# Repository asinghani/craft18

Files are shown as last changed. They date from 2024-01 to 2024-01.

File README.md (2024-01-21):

# Craft18

Bring Minecraft Redstone circuits to life using Craft18, our physical re-creation of the game’s “circuit” mechanics using only discrete analog components. Look ma, no microcontrollers! To build even more complex circuits, link the physical world to the virtual world using our custom game plugin and game-to-physical bridge!

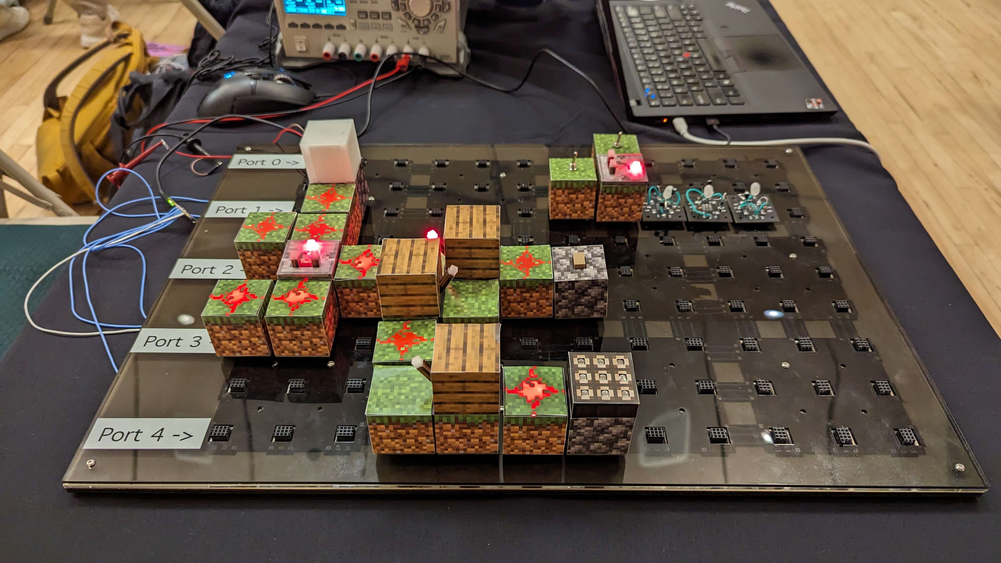
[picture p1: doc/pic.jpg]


Also see our [circuit diagrams PDF](doc/schem.pdf) to see how each circuit is implemented!

## Repo Structure

- [3D printable CAD models for each block](3d_cad/)
- [Texture images for each block](textures/)
- [Raw circuit schematic files](schematics/)
- [Spigot plugin for physical-to-virtual bridge](craft18_plugin/)
- [Software for physical-to-virtual bridge](craft18duino/)
- [Baseplate CAD files](2d_cad/)
- [Connector board layouts](boards/)

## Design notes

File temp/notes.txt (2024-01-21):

Blocks we need to build: (LxH)

btn height = 3.175mm + 2px = 7.9375mm ~= 7.9mm

btn = 8mm x 13mm

holes 5.7mm apart

holes 2.8mm high
holes 1.1mm wide

btn profile = 
10.3mm x 4.8mm

minus 3.5mm hole on one 10.3mm side

16px = 1.5in = 38.1mm

1px = 0.09375in = 2.38125mm

plate thickness (top of base plate to bottom of block plate):
0.428in

account for screw head diameter as well

repeater torch bottom hole
1/8" x 1/8" x 0.2in

- iron door textures: 4
- torch side textures: 90
- torch top textures: 30

- grass side textures: 150
- grass top textures: 10

- wood textures: 30
- cobblestone textures: 25
- repeater top textures: 8
- comparator top textures: 8
- repeater/comparator side textures: 35

- redstone lamp textures: 20

- redstone dust X textures: 20
- redstone dust line textures: 10

- daylight sensor top textures: 2
- daylight sensor side textures: 6

1 iron door (1x3)
	- grass block + iron door on top + space for servo
	- need to measure out servo dimensions to figure out fit

repeater slider top half (small)
button top half (small)
lever stone piece (small)

print more torch tops
print more 5mm diffusers

daylight sensor print ring + top half

5mm LED diffuser attempt (small, PETG)

make 14x torch caps

3 torches (2x2) ++
	- 2x grass block (base) + some block (wood) + torch on the side

5 repeaters (1x1.5) ++
	- grass block with repeater on top with switch + output indicator LED in the repeater

2 comparators (1x1.5) ++
	- grass block with comparator on top with + 2x output indicator LEDs on the back + always-on LED in the front

1 button (1x1.5) **** ++
	- grass block + up facing wooden button
	- button = 14.2875 W x 9.525 L x 4.7625 H
		     = 6 x 

3 levers (1x1.5) **** ++
	- grass block + up facing lever switch
	- lever base = 19.05 W x 14.2875 L x 7.14375 H
				 = 8 x 6 x 3

2 redstone lamps (1x2) **** ++
	- grass block + hollow-ish redstone lamp
	- top half printed in translucent
	- bottom half is generic block with round hole

1 daylight sensor (1x1.5) 
	- grass block + daylight sensor texture + 9x photocell
	- see solidworks file for top half
	- bottom half is generic block with round hole
	- height = 6px // 14.2875mm
	- 3.5mm base test = 1.5px

15 redstone dust (1x1)  ****
	- 3 straight 12 X
	- grass block + redstone dust + holes for light to shine through

Textures we need:
	- green grass textures (all 6 sides)
		- make sure it matches the game, the textures in the file are inconsistent
	- comparator textures
	- block-side-mount torch textures
	- redstone lamp textures
	- iron door textures
	- redstone dust on grass textures (note there's 2 separate textures for X axis and Y axis)
	- redstone dust "cross" on grass textures
	- wooden button texture
	- lever textures
	- daylight sensor texture
	- note block texture

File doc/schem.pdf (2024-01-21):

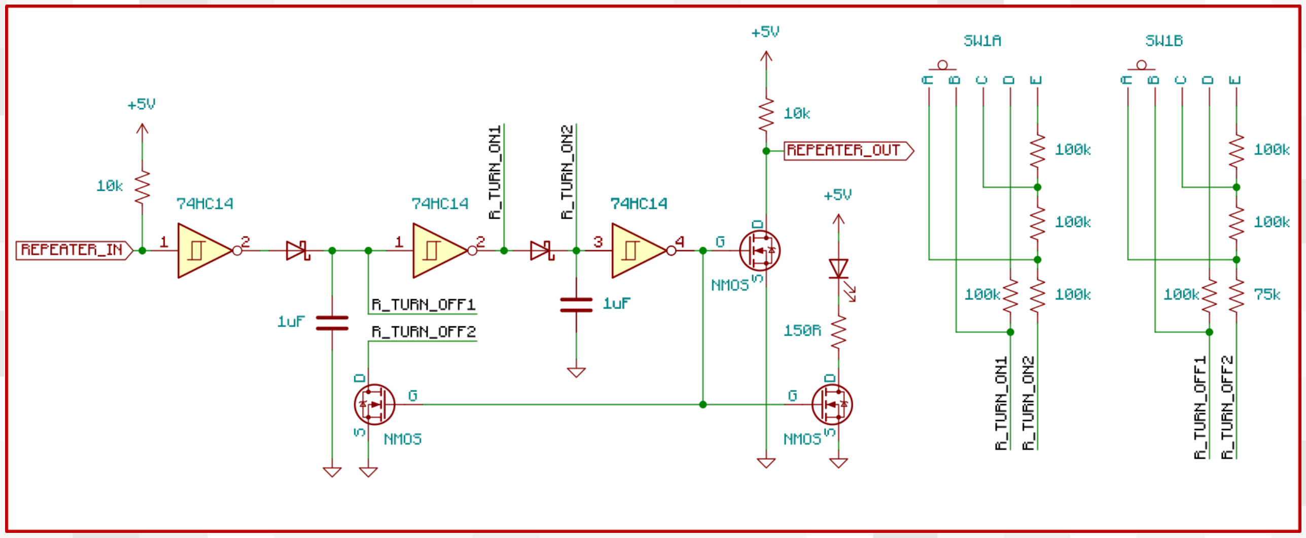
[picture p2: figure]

# Repeater

Produces a full-strength output signal (https://minecraft.wiki/w/Redstone_Dust) from its front when its back is powered, with four configurable delay settings.

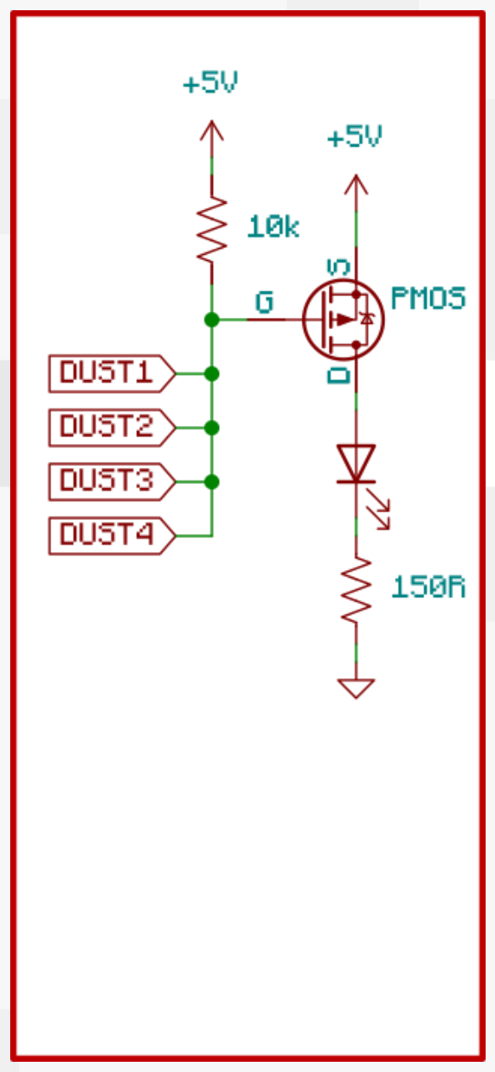
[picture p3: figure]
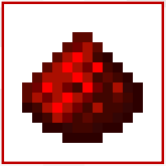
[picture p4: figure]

# Redstone Dust

Can transmit redstone power as a wire when placed as a block.

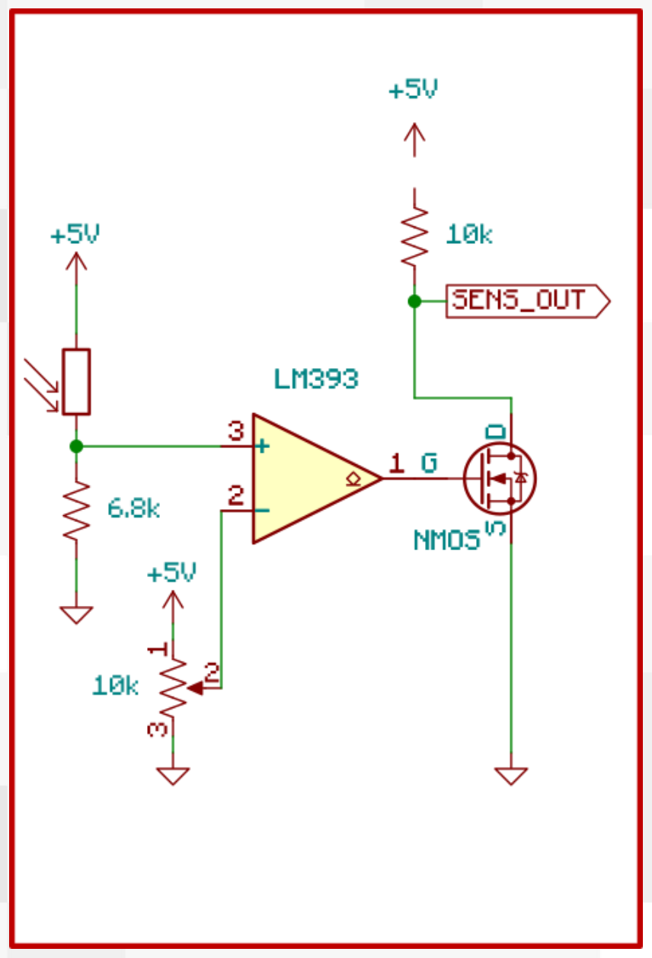
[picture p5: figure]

# Daylight Detector

Outputs a redstone signal based on sunlight.

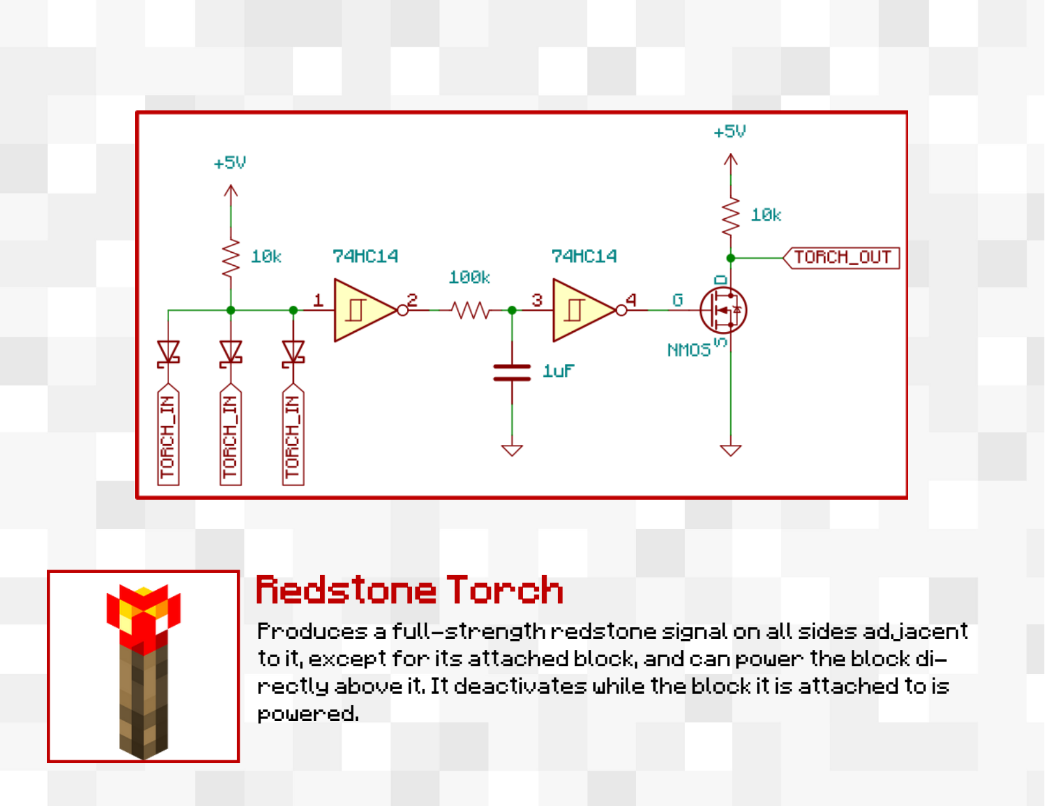
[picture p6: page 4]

# Redstone Torch

Produces a full-strength redstone signal on all sides adjacent to it, except for its attached block, and can power the block directly above it. It deactivates while the block it is attached to is powered.

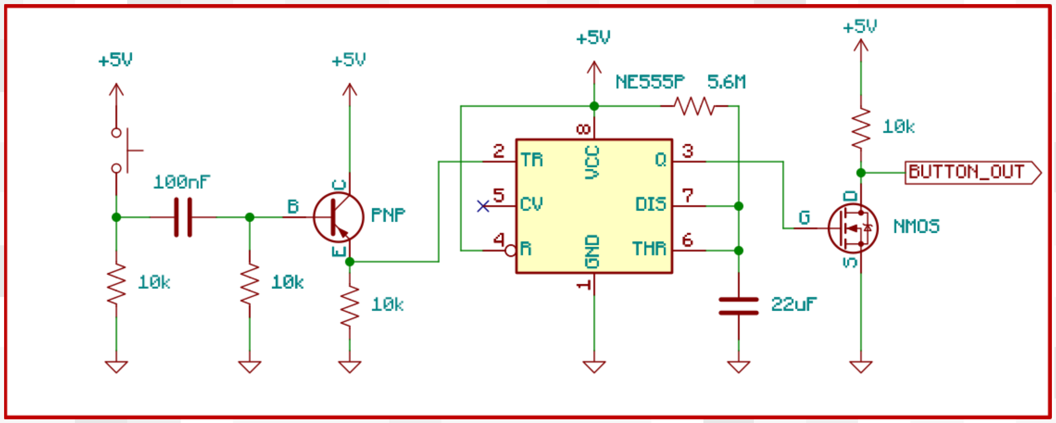
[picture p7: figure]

# Button

Produces a temporary redstone signal when pressed.

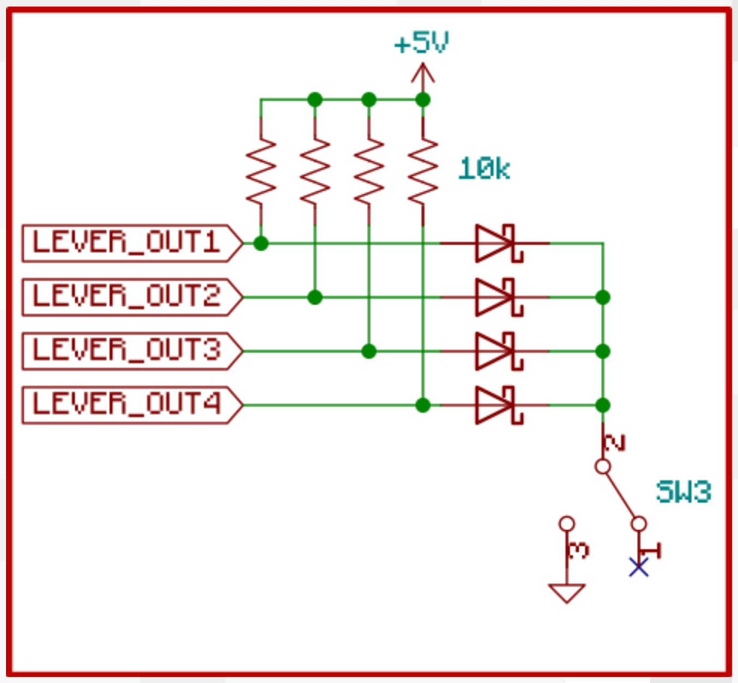
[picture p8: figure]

# Lever

Can provide switchable redstone power.

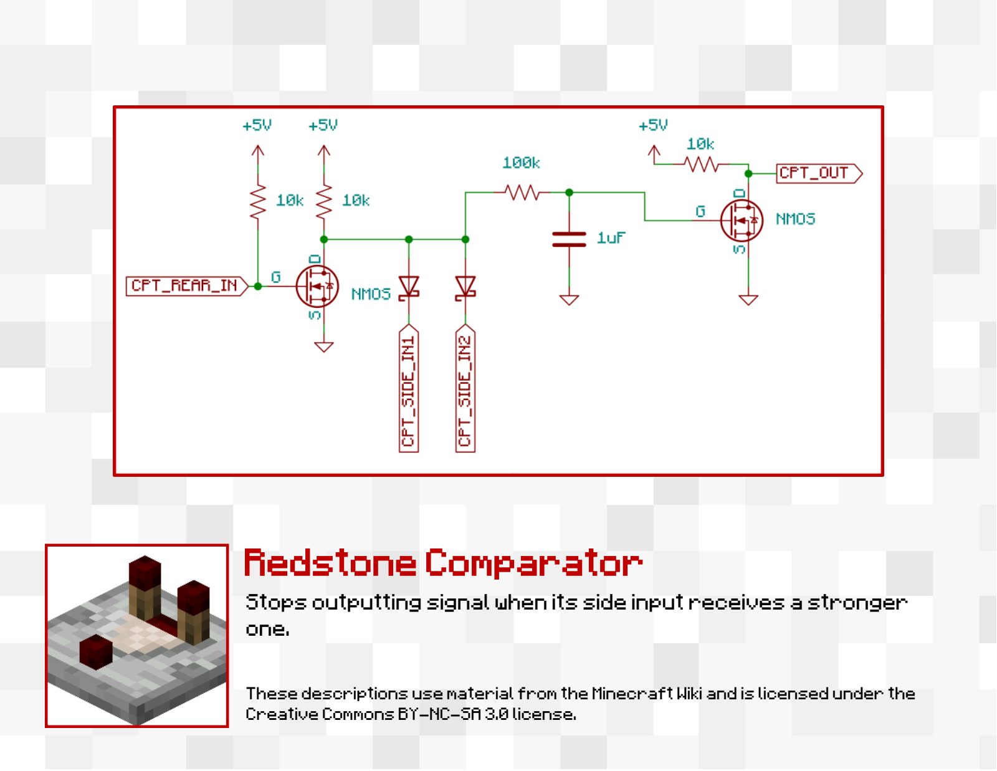
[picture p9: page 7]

# Redstone Comparator

Stops outputting signal when its side input receives a stronger one.

These descriptions use material from the Minecraft Wiki and is licensed under the Creative Commons BY-NC-SA 3.0 license.

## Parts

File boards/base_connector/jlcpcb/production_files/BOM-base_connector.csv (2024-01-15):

Comment | Designator | Footprint | LCSC
MountingHole | H2 | MountingHole_3.2mm_M3
DNF | R8 | R_0805_2012Metric_Pad1.20x1.40mm_HandSolder
VCC | TP5 | TestPoint_THTPad_2.5x2.5mm_Drill1.2mm
TestPoint | TP1 | TestPoint_THTPad_2.5x2.5mm_Drill1.2mm
GND | TP7 | TestPoint_THTPad_2.5x2.5mm_Drill1.2mm
MountingHole | H1 | MountingHole_3.2mm_M3
DNF | R7 | R_0805_2012Metric_Pad1.20x1.40mm_HandSolder
MountingHole | H4 | MountingHole_3.2mm_M3
DNF | R2 | R_0805_2012Metric_Pad1.20x1.40mm_HandSolder
~ | U1 | 3x3conn
DNF | R5 | R_0805_2012Metric_Pad1.20x1.40mm_HandSolder
TestPoint | TP4 | TestPoint_THTPad_2.5x2.5mm_Drill1.2mm
VCC | TP6 | TestPoint_THTPad_2.5x2.5mm_Drill1.2mm
TestPoint | TP3 | TestPoint_THTPad_2.5x2.5mm_Drill1.2mm
DNF | R4 | R_0805_2012Metric_Pad1.20x1.40mm_HandSolder
GND | TP8 | TestPoint_THTPad_2.5x2.5mm_Drill1.2mm
DNF | R1 | R_0805_2012Metric_Pad1.20x1.40mm_HandSolder
MountingHole | H3 | MountingHole_3.2mm_M3
TestPoint | TP2 | TestPoint_THTPad_2.5x2.5mm_Drill1.2mm
DNF | R3 | R_0805_2012Metric_Pad1.20x1.40mm_HandSolder
DNF | R6 | R_0805_2012Metric_Pad1.20x1.40mm_HandSolder

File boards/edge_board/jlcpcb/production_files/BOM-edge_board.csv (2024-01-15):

Comment | Designator | Footprint | LCSC
MountingHole | H2 | MountingHole_2.2mm_M2
MountingHole | H4 | MountingHole_2.2mm_M2
Conn_01x03 | J2 | connfemale
MountingHole | H3 | MountingHole_2.2mm_M2
MountingHole | H1 | MountingHole_2.2mm_M2
Conn_01x03 | J1 | connmale
SIG | TP2 | TestPoint_THTPad_3.0x3.0mm_Drill1.5mm
R_US | R1 | R_0805_2012Metric_Pad1.20x1.40mm_HandSolder
VCC | TP1 | TestPoint_THTPad_3.0x3.0mm_Drill1.5mm
GND | TP3 | TestPoint_THTPad_3.0x3.0mm_Drill1.5mm
R_US | R2 | R_0805_2012Metric_Pad1.20x1.40mm_HandSolder

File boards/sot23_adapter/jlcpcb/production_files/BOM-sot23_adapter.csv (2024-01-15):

Comment | Designator | Footprint | LCSC
Conn_01x03 | J3 | PinHeader_1x03_P2.54mm_Vertical
Conn_01x03 | J2 | PinHeader_1x03_P2.54mm_Vertical
SOT23 | J1 | TSOT-23-6_HandSoldering

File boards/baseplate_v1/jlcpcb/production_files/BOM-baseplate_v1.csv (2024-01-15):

Comment | Designator | Footprint | LCSC
TestPoint | TP9 | edge_pad
~ | U9 | 3x3conn
TestPoint | TP35 | edge_pad
TestPoint | TP11 | edge_pad
~ | U5 | 3x3conn
~ | U1 | 3x3conn
TestPoint | TP5 | edge_pad
TestPoint | TP25 | edge_pad
TestPoint | TP4 | edge_pad
~ | U4 | 3x3conn
TestPoint | TP20 | edge_pad
~ | U8 | 3x3conn
TestPoint | TP26 | edge_pad
TestPoint | TP31 | edge_pad
~ | U3 | 3x3conn
~ | U2 | 3x3conn
TestPoint | TP16 | edge_pad
TestPoint | TP27 | edge_pad
TestPoint | TP17 | edge_pad
TestPoint | TP8 | edge_pad
TestPoint | TP7 | edge_pad
TestPoint | TP19 | edge_pad
TestPoint | TP18 | edge_pad
TestPoint | TP34 | edge_pad
TestPoint | TP6 | edge_pad
TestPoint | TP12 | edge_pad
TestPoint | TP2 | edge_pad
TestPoint | TP15 | edge_pad
TestPoint | TP32 | edge_pad
TestPoint | TP30 | edge_pad
TestPoint | TP10 | edge_pad
~ | U7 | 3x3conn
TestPoint | TP29 | edge_pad
~ | U6 | 3x3conn
TestPoint | TP36 | edge_pad
TestPoint | TP28 | edge_pad
TestPoint | TP14 | edge_pad
TestPoint | TP1 | edge_pad
TestPoint | TP22 | edge_pad
TestPoint | TP33 | edge_pad
TestPoint | TP24 | edge_pad
TestPoint | TP13 | edge_pad
TestPoint | TP23 | edge_pad
TestPoint | TP21 | edge_pad
TestPoint | TP3 | edge_pad

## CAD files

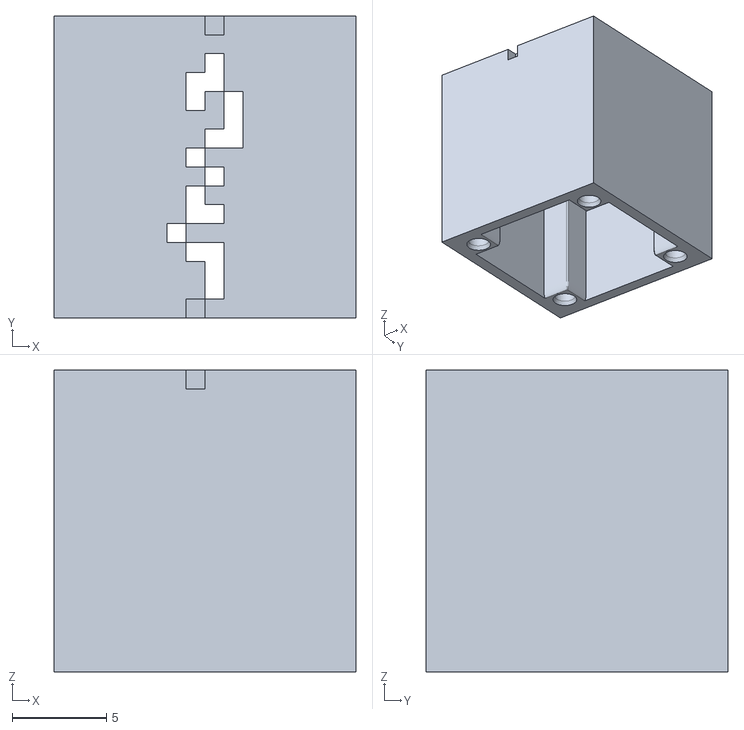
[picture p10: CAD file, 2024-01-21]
3d_cad/redstone_wire_straight.stl
16.0 x 16.0 x 16.0

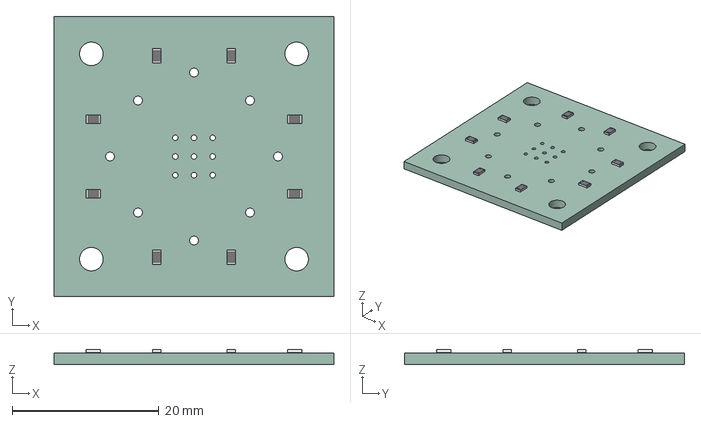
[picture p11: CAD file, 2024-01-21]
boards/base_connector/base_connector.step
38.1 x 38.1 x 2.10 mm
base_connector PCB

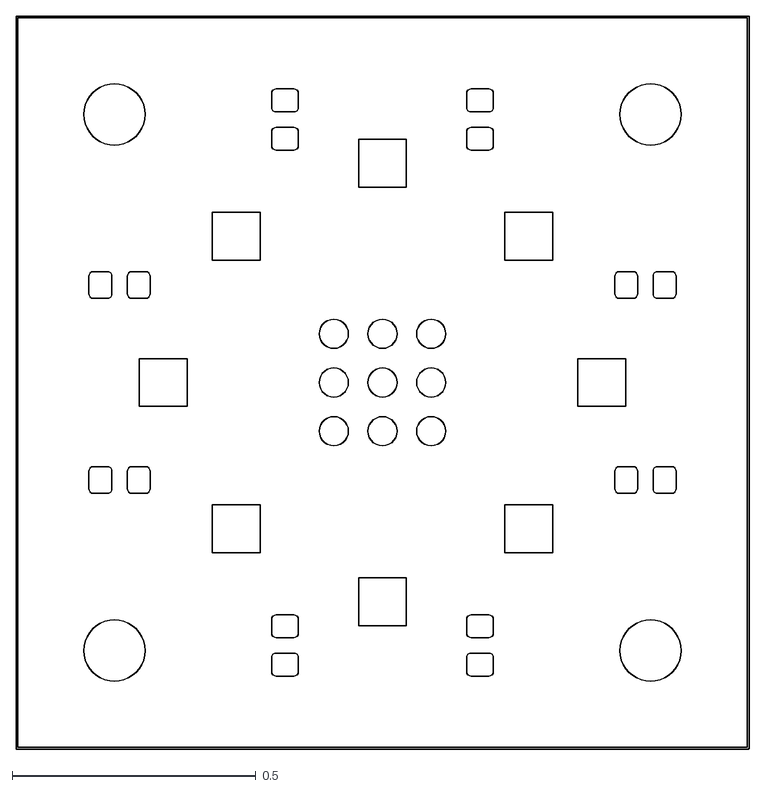
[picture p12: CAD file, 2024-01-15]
boards/base_connector/dxf/base_connector-Edge_Cuts.dxf
1.50 x 1.50

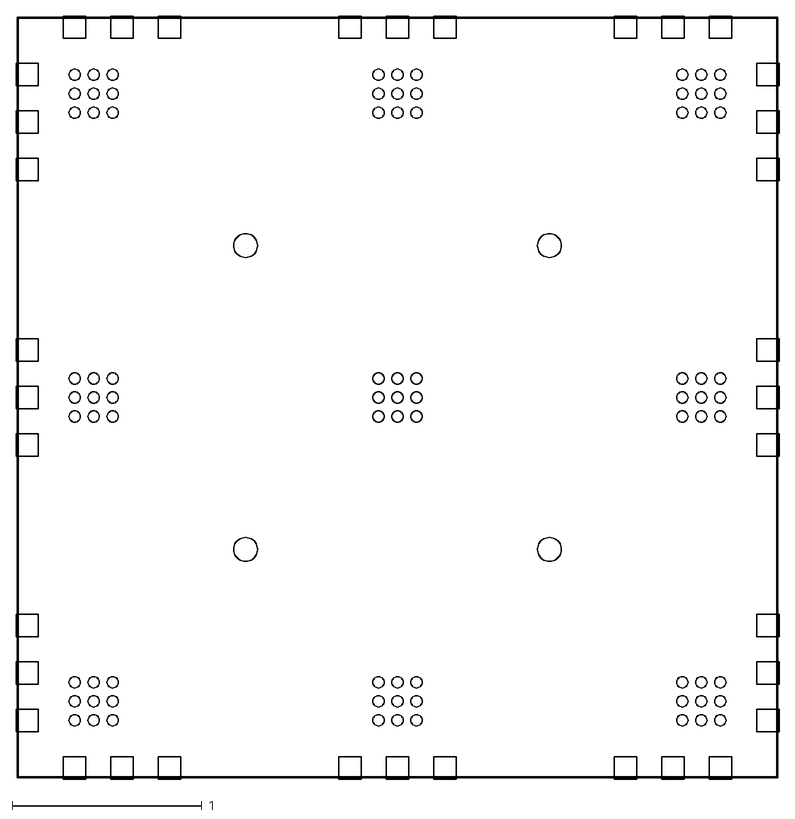
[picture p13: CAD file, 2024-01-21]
boards/baseplate_v1/dxf/baseplate_v1-Edge_Cuts.dxf
4.02 x 4.02

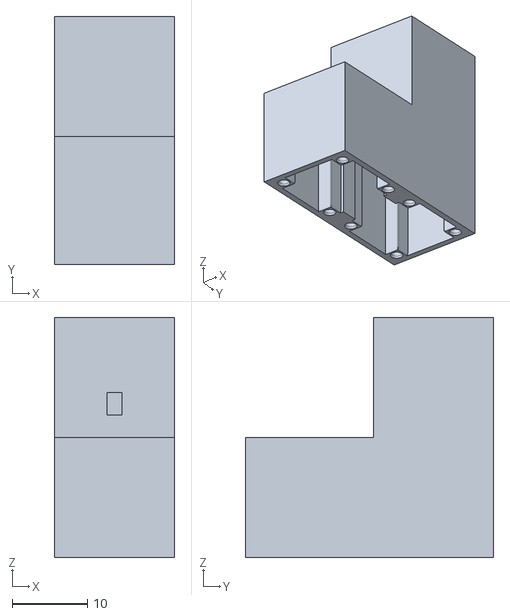
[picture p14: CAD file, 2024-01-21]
3d_cad/torch_base.stl
16.0 x 33.0 x 32.0

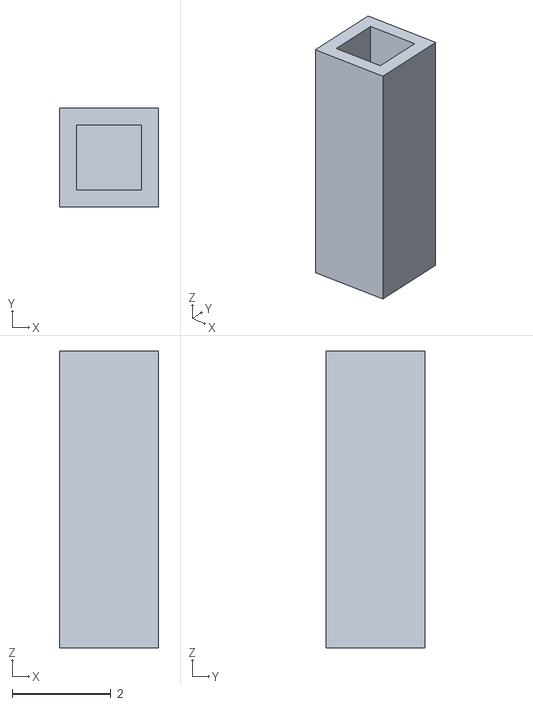
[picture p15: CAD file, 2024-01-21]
3d_cad/repeater_switch_cap.stl
2.00 x 2.00 x 6.00

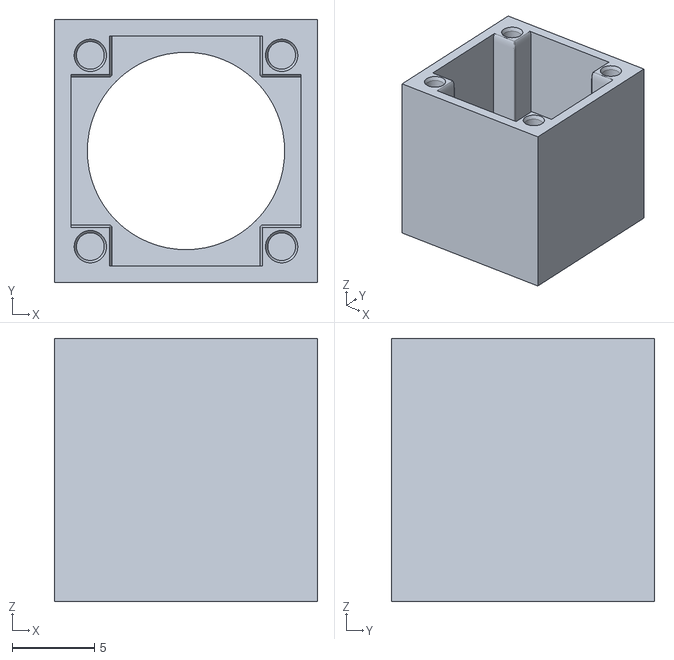
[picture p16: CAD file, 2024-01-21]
3d_cad/generic_bottom_half.stl
16.0 x 16.0 x 16.0

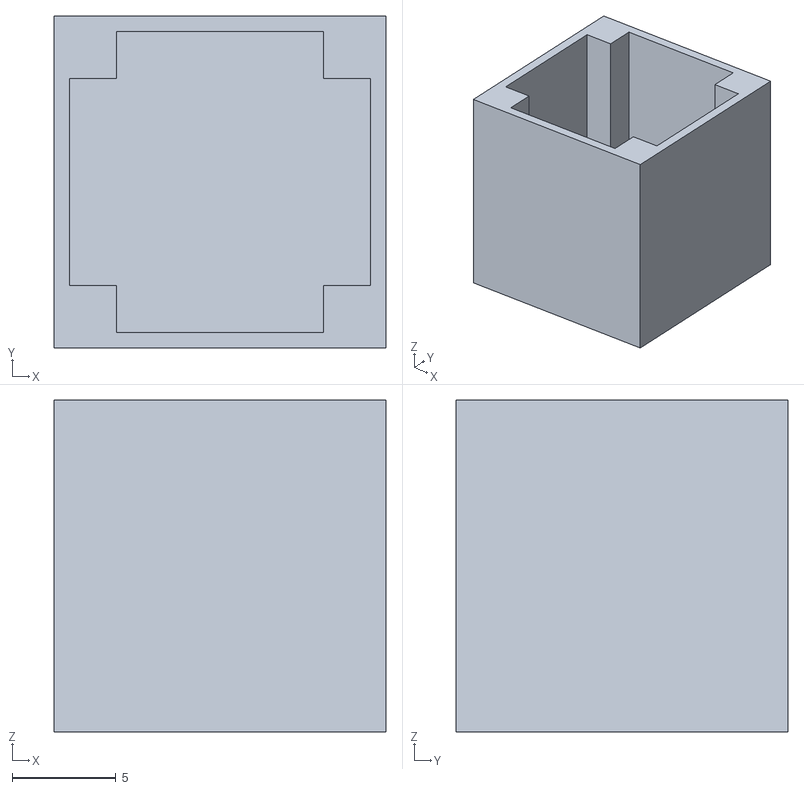
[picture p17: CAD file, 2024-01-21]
3d_cad/lamp_top_transparent.stl
16.0 x 16.0 x 16.0

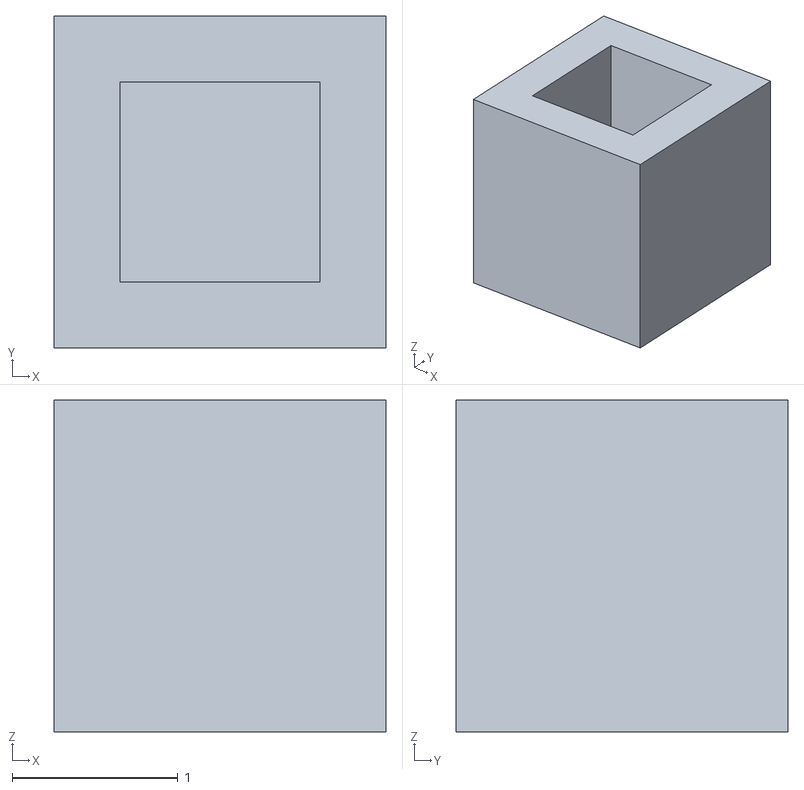
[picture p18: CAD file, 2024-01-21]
3d_cad/redstone_torch_cap.stl
2.00 x 2.00 x 2.00

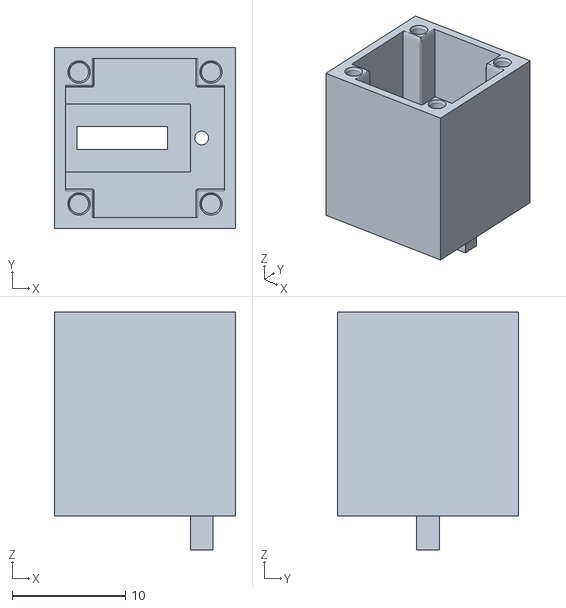
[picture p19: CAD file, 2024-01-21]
3d_cad/repeater.stl
16.0 x 16.0 x 21.0

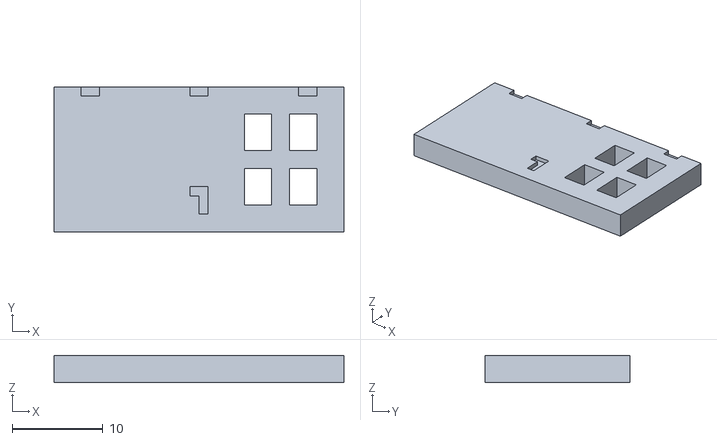
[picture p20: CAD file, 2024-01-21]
3d_cad/door.stl
32.0 x 16.0 x 3.00

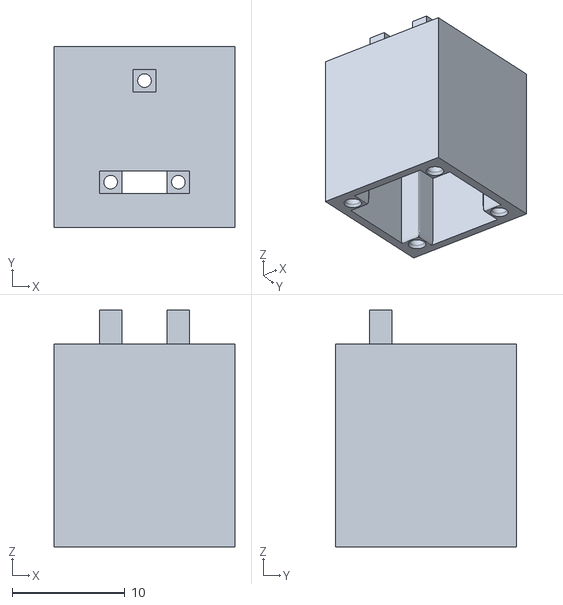
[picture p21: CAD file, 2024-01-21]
3d_cad/comparator.stl
16.0 x 16.0 x 21.0

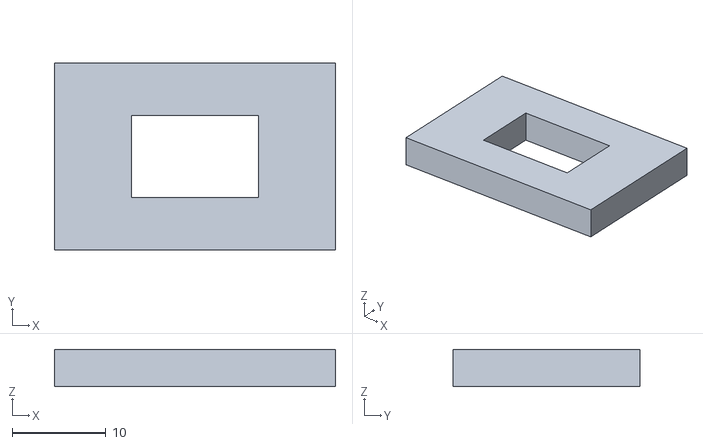
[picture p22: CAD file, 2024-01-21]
3d_cad/button_spacer_prescaled.stl
30.0 x 20.0 x 4.00

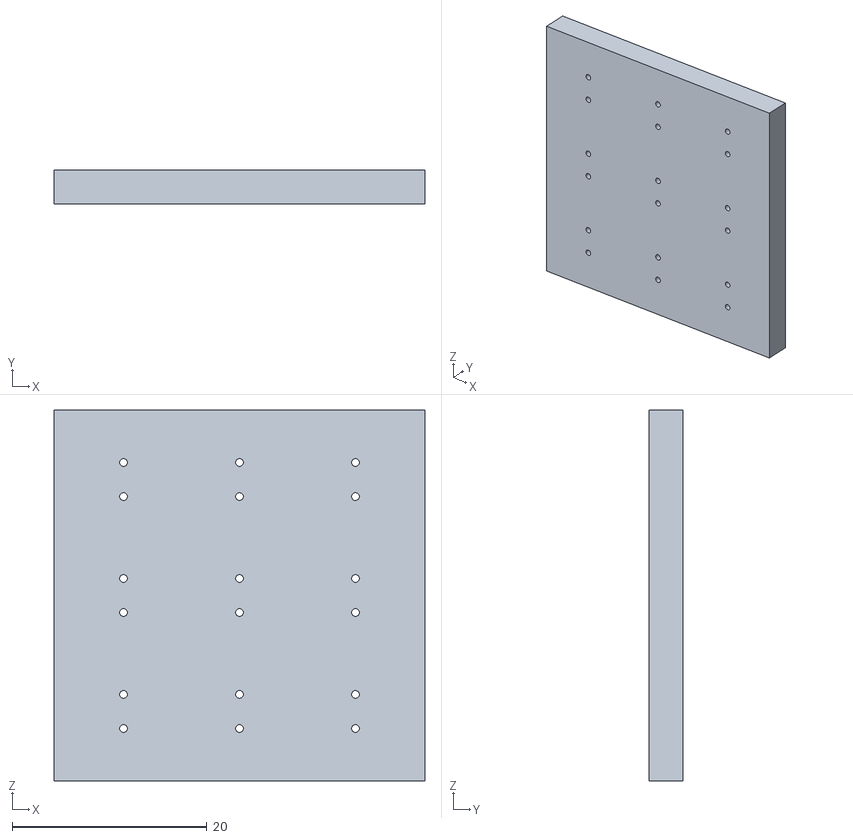
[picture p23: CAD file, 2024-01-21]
3d_cad/daylight_sensor_top.STL
38.1 x 3.50 x 38.1

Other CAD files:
2d_cad/base_board.dwg
3d_cad/button.stl
3d_cad/redstone_wire_cross.stl
3d_cad/lever.stl
3d_cad/button_top_prescaled.stl
3d_cad/daylight_sensor_frame.stl
3d_cad/torch_light.stl
boards/base_connector/dxf/base_connector-B_Mask.dxf
boards/base_connector/dxf/base_connector-F_Mask.dxf

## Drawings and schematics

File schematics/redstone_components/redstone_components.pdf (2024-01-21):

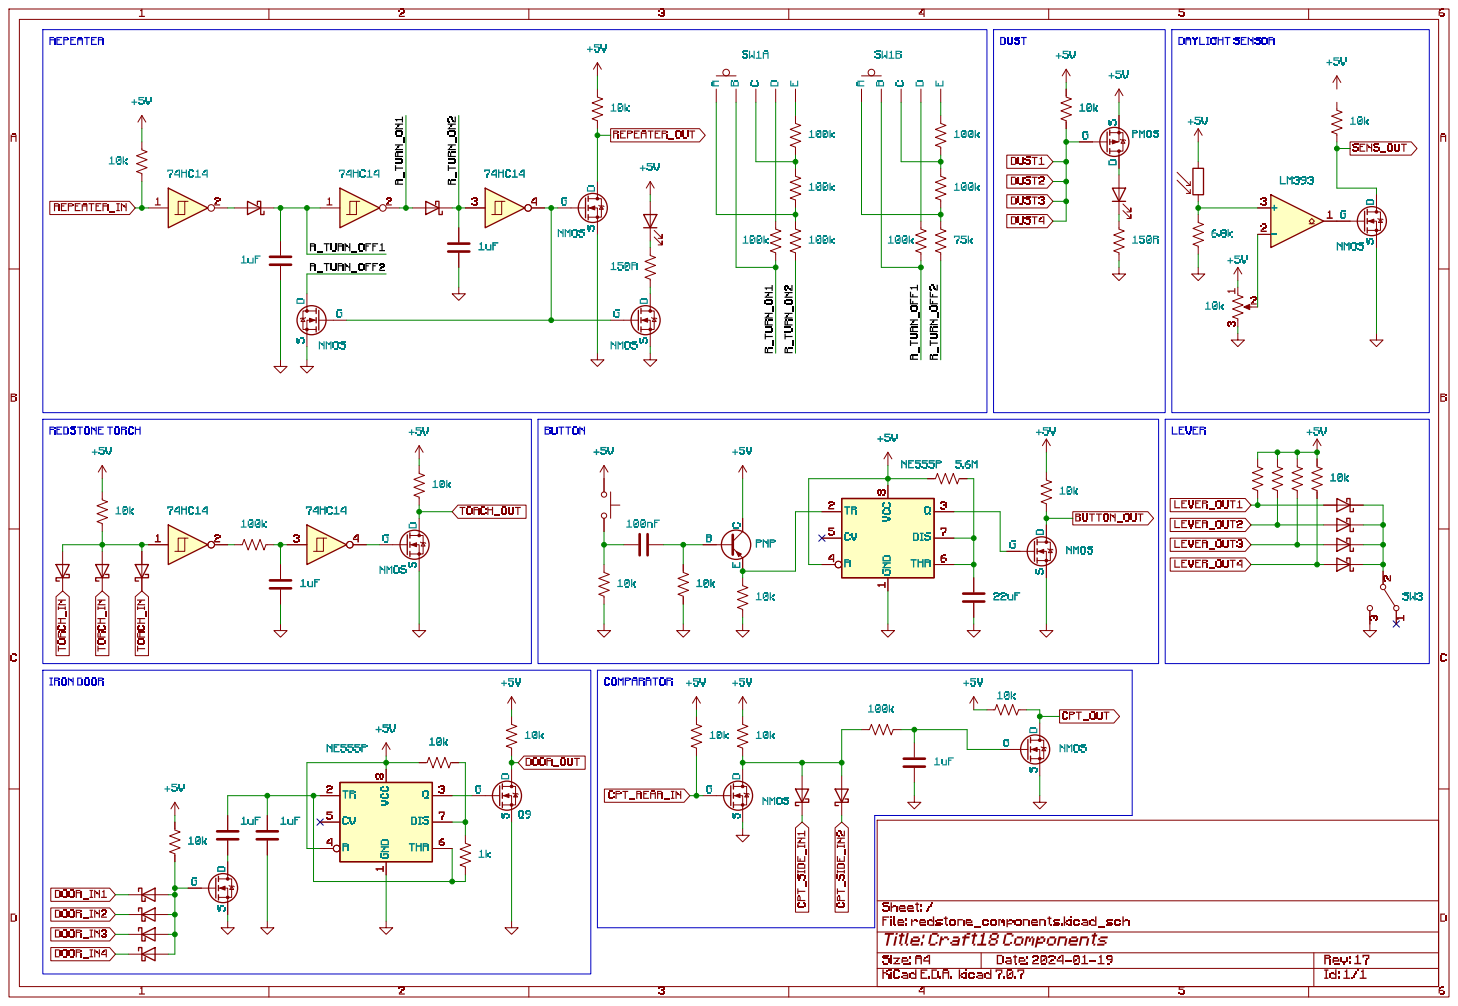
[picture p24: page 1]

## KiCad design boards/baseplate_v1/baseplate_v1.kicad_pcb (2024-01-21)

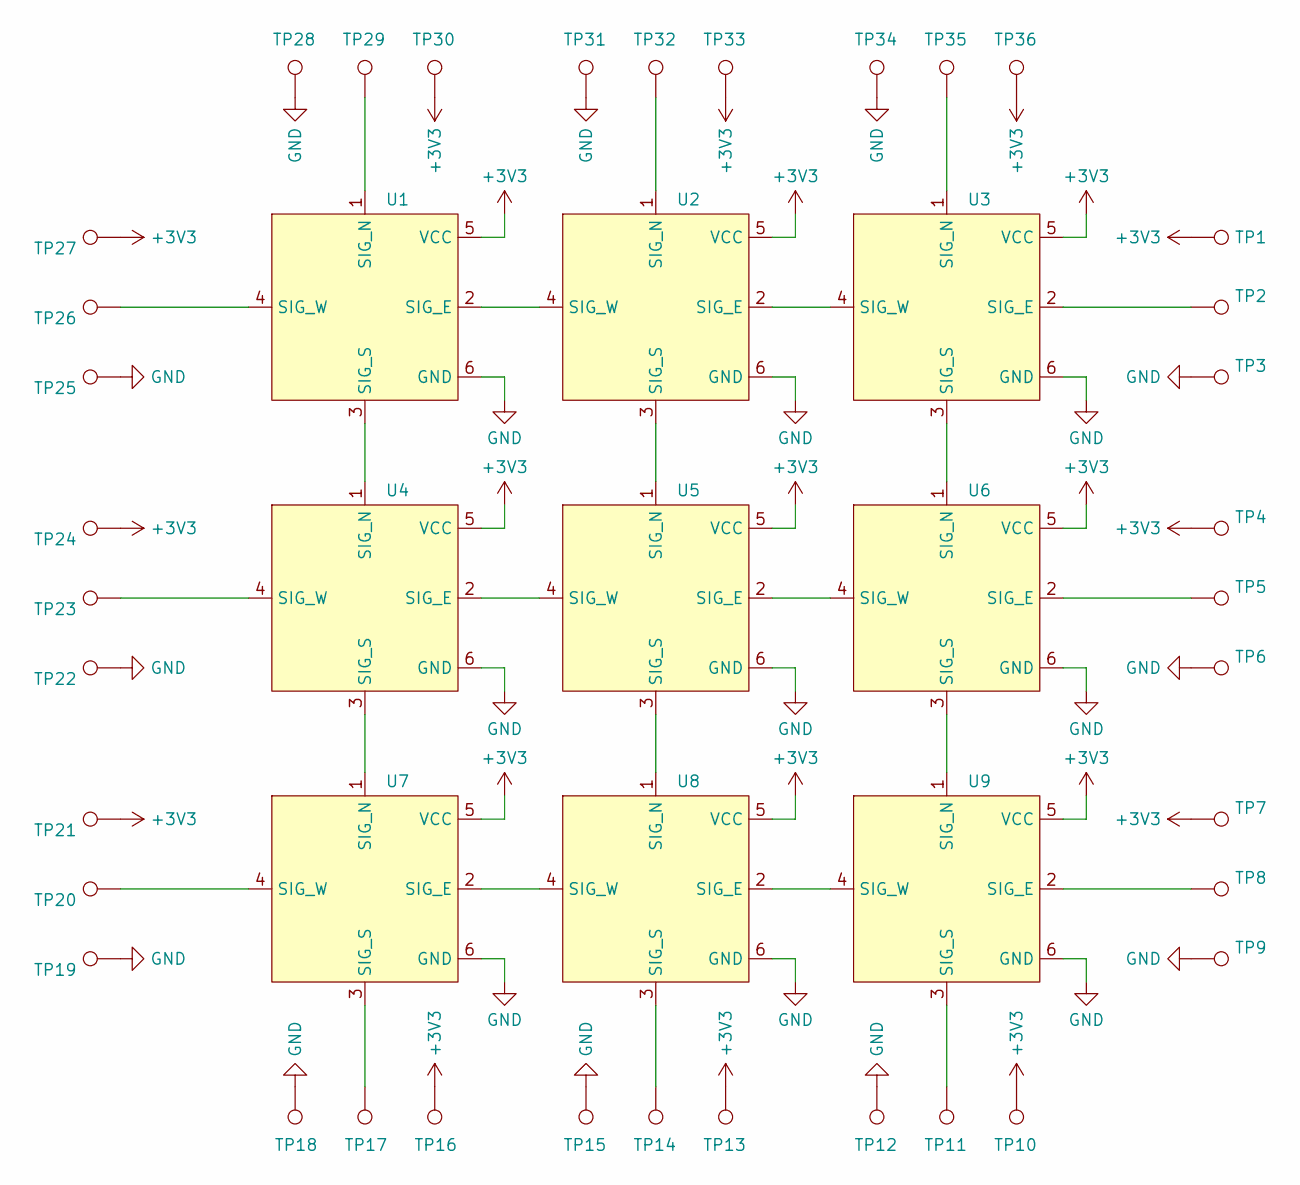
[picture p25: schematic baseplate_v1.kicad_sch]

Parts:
TP1, TP2, TP3, TP4, TP5, TP6, TP7, TP8, TP9, TP10, TP11, TP12, TP13, TP14, TP15, TP16, TP17, TP18, TP19, TP20, TP21, TP22, TP23, TP24, TP25, TP26, TP27, TP28, TP29, TP30, TP31, TP32, TP33, TP34, TP35, TP36: TestPoint; edge_pad
U1, U2, U3, U4, U5, U6, U7, U8, U9: 3x3conn

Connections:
+3V3: TP1.1, TP4.1, TP7.1, TP10.1, TP13.1, TP16.1, TP21.1, TP24.1, TP27.1, TP30.1, TP33.1, TP36.1, U1.5 (VCC), U2.5 (VCC), U3.5 (VCC), U4.5 (VCC), U5.5 (VCC), U6.5 (VCC), U7.5 (VCC), U8.5 (VCC), U9.5 (VCC)
GND: TP3.1, TP6.1, TP9.1, TP12.1, TP15.1, TP18.1, TP19.1, TP22.1, TP25.1, TP28.1, TP31.1, TP34.1, U1.6 (GND), U2.6 (GND), U3.6 (GND), U4.6 (GND), U5.6 (GND), U6.6 (GND), U7.6 (GND), U8.6 (GND), U9.6 (GND)
unnamed: U1.2 (SIG_E), U2.4 (SIG_W)
unnamed: TP29.1, U1.1 (SIG_N)
unnamed: U1.3 (SIG_S), U4.1 (SIG_N)
unnamed: TP26.1, U1.4 (SIG_W)
unnamed: U2.2 (SIG_E), U3.4 (SIG_W)
unnamed: TP32.1, U2.1 (SIG_N)
unnamed: U2.3 (SIG_S), U5.1 (SIG_N)
unnamed: TP2.1, U3.2 (SIG_E)
unnamed: TP35.1, U3.1 (SIG_N)
unnamed: U3.3 (SIG_S), U6.1 (SIG_N)
unnamed: U4.2 (SIG_E), U5.4 (SIG_W)
unnamed: U4.3 (SIG_S), U7.1 (SIG_N)
unnamed: TP23.1, U4.4 (SIG_W)
unnamed: U5.2 (SIG_E), U6.4 (SIG_W)
unnamed: U5.3 (SIG_S), U8.1 (SIG_N)
unnamed: TP5.1, U6.2 (SIG_E)
unnamed: U6.3 (SIG_S), U9.1 (SIG_N)
unnamed: U7.2 (SIG_E), U8.4 (SIG_W)
unnamed: TP17.1, U7.3 (SIG_S)
unnamed: TP20.1, U7.4 (SIG_W)
unnamed: U8.2 (SIG_E), U9.4 (SIG_W)
unnamed: TP14.1, U8.3 (SIG_S)
unnamed: TP8.1, U9.2 (SIG_E)
unnamed: TP11.1, U9.3 (SIG_S)

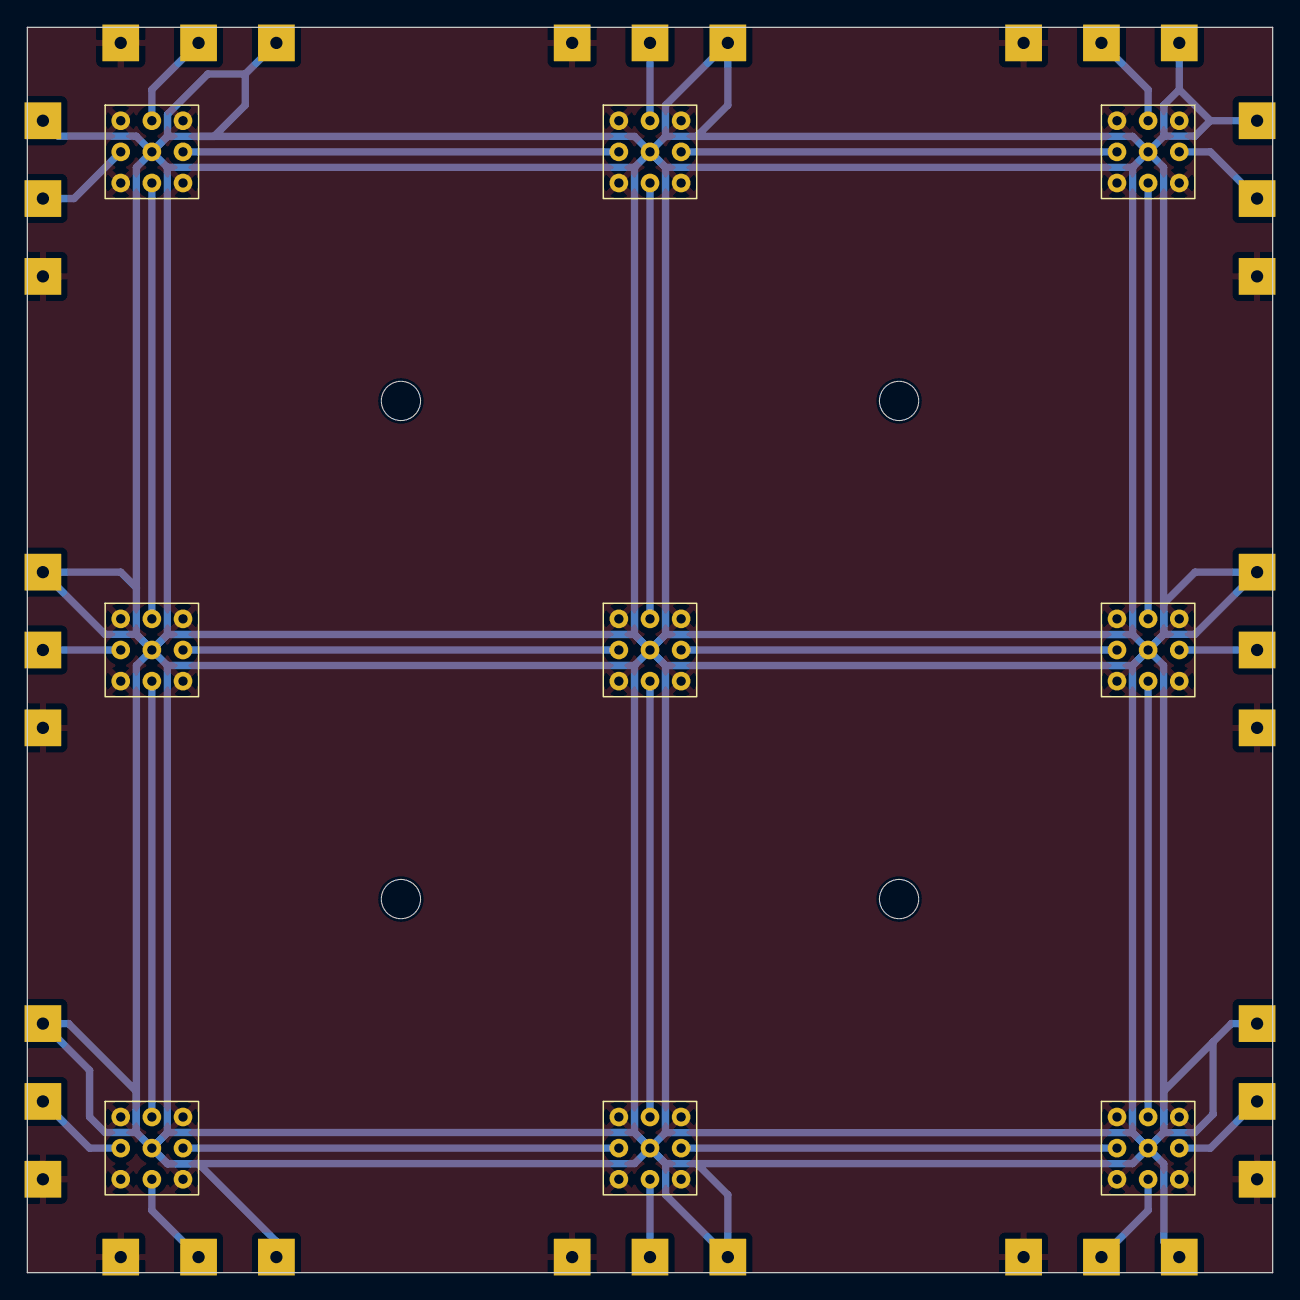
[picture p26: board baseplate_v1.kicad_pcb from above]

Board: 2 copper layers, 101.6 x 101.6 mm, 45 parts (0 on the bottom side), 26 nets.

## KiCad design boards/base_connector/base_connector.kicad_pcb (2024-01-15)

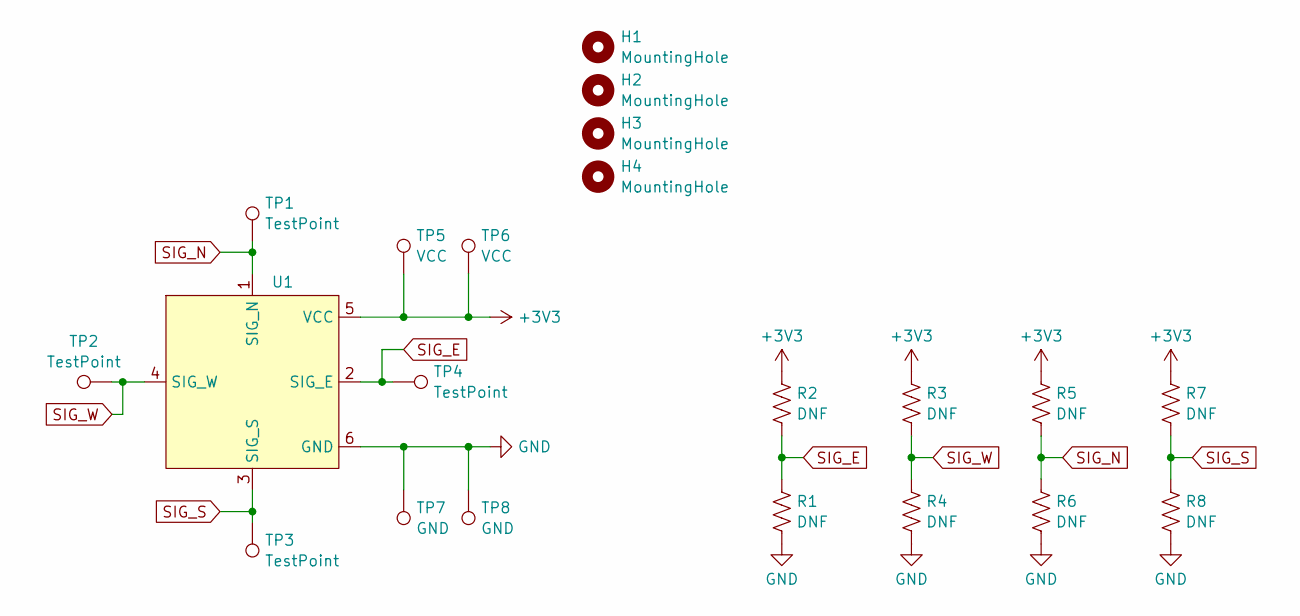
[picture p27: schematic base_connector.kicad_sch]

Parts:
H1, H2, H3, H4: MountingHole; MountingHole_3.2mm_M3
R1, R2, R3, R4, R5, R6, R7, R8: DNF; R_0805_2012Metric_Pad1.20x1.40mm_HandSolder
TP1, TP2, TP3, TP4: TestPoint; TestPoint_THTPad_2.5x2.5mm_Drill1.2mm
TP5, TP6: VCC; TestPoint_THTPad_2.5x2.5mm_Drill1.2mm
TP7, TP8: GND; TestPoint_THTPad_2.5x2.5mm_Drill1.2mm
U1: 3x3conn

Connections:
+3V3: R2.2, R3.2, R5.2, R7.2, TP5.1, TP6.1, U1.5 (VCC)
GND: R1.1, R4.1, R6.1, R8.1, TP7.1, TP8.1, U1.6 (GND)
SIG_E: R1.2, R2.1, TP4.1, U1.2 (SIG_E)
SIG_N: R5.1, R6.2, TP1.1, U1.1 (SIG_N)
SIG_S: R7.1, R8.2, TP3.1, U1.3 (SIG_S)
SIG_W: R3.1, R4.2, TP2.1, U1.4 (SIG_W)

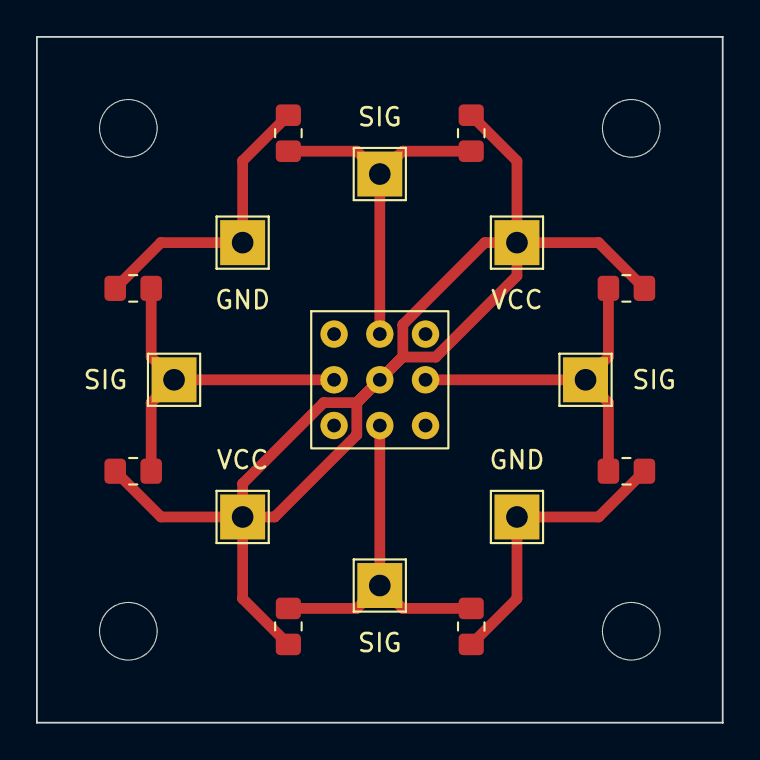
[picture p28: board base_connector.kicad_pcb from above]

Board: 2 copper layers, 38.1 x 38.1 mm, 21 parts (0 on the bottom side), 6 nets.

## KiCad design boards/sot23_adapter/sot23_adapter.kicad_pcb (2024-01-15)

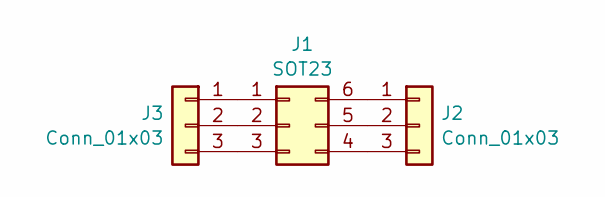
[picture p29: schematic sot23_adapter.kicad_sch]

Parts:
J1: SOT23; TSOT-23-6_HandSoldering
J2, J3: Conn_01x03; PinHeader_1x03_P2.54mm_Vertical

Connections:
unnamed: J1.1, J3.1
unnamed: J1.2, J3.2
unnamed: J1.3, J3.3
unnamed: J1.4, J2.3
unnamed: J1.5, J2.2
unnamed: J1.6, J2.1

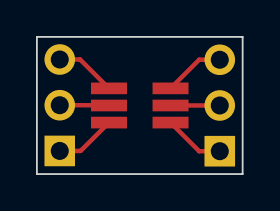
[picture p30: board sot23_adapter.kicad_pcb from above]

Board: 2 copper layers, 11.4 x 7.6 mm, 3 parts (0 on the bottom side), 6 nets.

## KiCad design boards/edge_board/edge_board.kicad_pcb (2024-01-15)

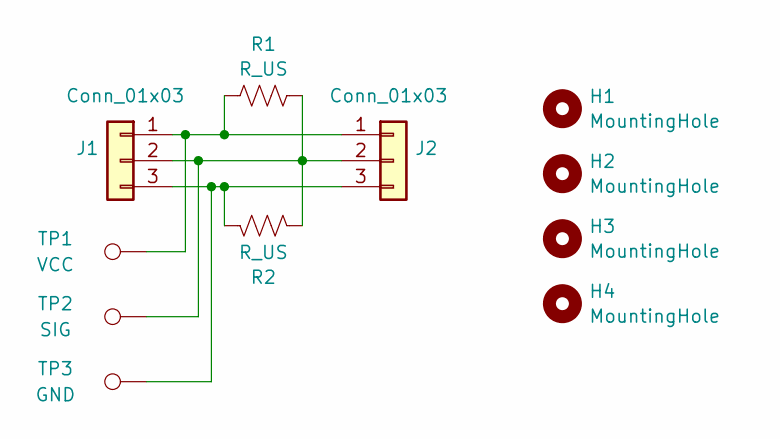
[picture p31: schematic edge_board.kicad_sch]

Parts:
H1, H2, H3, H4: MountingHole; MountingHole_2.2mm_M2
J1: Conn_01x03; connmale
J2: Conn_01x03; connfemale
R1, R2: R_US; R_0805_2012Metric_Pad1.20x1.40mm_HandSolder
TP1: VCC; TestPoint_THTPad_3.0x3.0mm_Drill1.5mm
TP2: SIG; TestPoint_THTPad_3.0x3.0mm_Drill1.5mm
TP3: GND; TestPoint_THTPad_3.0x3.0mm_Drill1.5mm

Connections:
unnamed: J1.1, J2.1, R1.1, TP1.1
unnamed: J1.2, J2.2, R1.2, R2.1, TP2.1
unnamed: J1.3, J2.3, R2.2, TP3.1

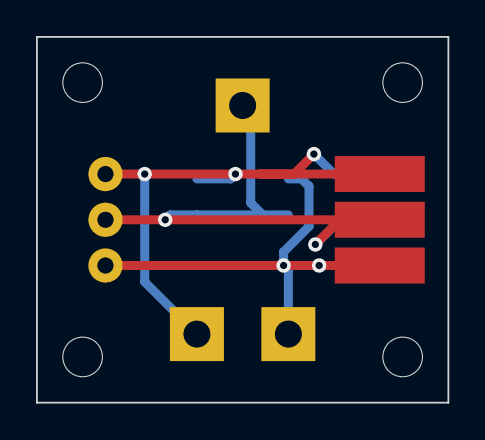
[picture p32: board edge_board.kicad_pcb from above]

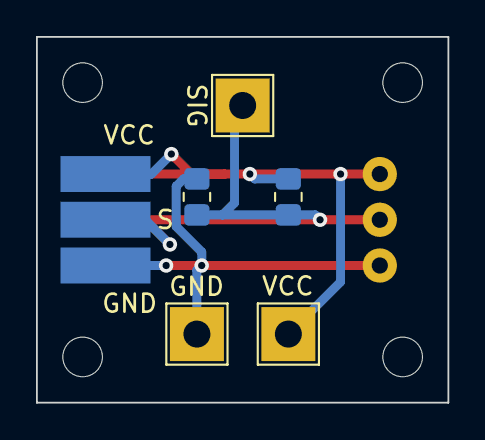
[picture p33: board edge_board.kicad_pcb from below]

Board: 2 copper layers, 22.9 x 20.3 mm, 11 parts (5 on the bottom side), 3 nets.

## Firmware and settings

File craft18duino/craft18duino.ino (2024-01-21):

#define PORT0 2
#define PORT1 3
#define PORT2 4
#define PORT3 5
#define PORT4 6

void setup() {
  digitalWrite(PORT0, LOW);
  digitalWrite(PORT1, LOW);
  digitalWrite(PORT2, LOW);
  digitalWrite(PORT3, LOW);
  digitalWrite(PORT4, LOW);
  Serial.begin(115200);
}

int lastRead = 0;
void loop() {
  int x = lastRead;
  while (Serial.available()) {
    x = Serial.read();
  }
  if (x != lastRead) {
    pinMode(PORT0, (x & (1 << 0)) ? OUTPUT : INPUT_PULLUP);
    pinMode(PORT1, (x & (1 << 1)) ? OUTPUT : INPUT_PULLUP);
    pinMode(PORT2, (x & (1 << 2)) ? OUTPUT : INPUT_PULLUP);
    pinMode(PORT3, (x & (1 << 3)) ? OUTPUT : INPUT_PULLUP);
    pinMode(PORT4, (x & (1 << 4)) ? OUTPUT : INPUT_PULLUP);
    lastRead = x;
  }
  Serial.write(((!digitalRead(PORT0) << 0) |
                (!digitalRead(PORT1) << 1) |
                (!digitalRead(PORT2) << 2) |
                (!digitalRead(PORT3) << 3) |
                (!digitalRead(PORT4) << 4)) & ~lastRead);
  delay(2);
}

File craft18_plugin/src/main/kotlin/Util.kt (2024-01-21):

package xyz.gary600.craft18_plugin

import kotlinx.serialization.*
import kotlinx.serialization.builtins.IntArraySerializer
import kotlinx.serialization.descriptors.SerialDescriptor
import kotlinx.serialization.encoding.Decoder
import kotlinx.serialization.encoding.Encoder
import org.bukkit.Bukkit
import org.bukkit.Location

object LocationSerializer : KSerializer<Location> {
    private val delegateSerializer = IntArraySerializer()
    @OptIn(ExperimentalSerializationApi::class)
    override val descriptor: SerialDescriptor = SerialDescriptor("Location", delegateSerializer.descriptor)

    override fun serialize(encoder: Encoder, value: Location) {
        encoder.encodeSerializableValue(delegateSerializer, intArrayOf(value.blockX, value.blockY, value.blockZ))
    }

    override fun deserialize(decoder: Decoder): Location {
        val arr = decoder.decodeSerializableValue(delegateSerializer)
        if (arr.size != 3) throw SerializationException("invalid Location")
        return Location(Bukkit.getWorlds()[0], arr[0].toDouble(), arr[1].toDouble(), arr[2].toDouble())
    }
}

@Serializable
class Config(
    var ports: Array<@Serializable(with = LocationSerializer::class) Location?> = arrayOfNulls(5)
) {
    fun save() {
        if (!Craft18Plugin.plugin.dataFolder.exists()) Craft18Plugin.plugin.dataFolder.mkdirs()
        Craft18Plugin.plugin.configFile.writeText(Craft18Plugin.json.encodeToString(this))
    }

    companion object {
        fun load(): Config {
            return if (!Craft18Plugin.plugin.configFile.exists())
                Config().also { it.save() } // default
            else
                Craft18Plugin.json.decodeFromString(Craft18Plugin.plugin.configFile.readText())
        }
    }
}

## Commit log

2024-01-16 add plugin and arduino code
2024-01-16 add buttons
2024-01-20 add the rest of the pins for arduino
2024-01-21 add CAD files
    [base_board.dwg, base_connector.step, baseplate_v1-Edge_Cuts.dxf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]
2024-01-21 add additional CAD files
    [base_board.dwg]
2024-01-21 Add electronic schematics
    [redstone_components.kicad_pcb, redstone_components.kicad_sch]
2024-01-21 Add docs and make public
    [base_board.dwg, baseplate_v1.kicad_pcb]
